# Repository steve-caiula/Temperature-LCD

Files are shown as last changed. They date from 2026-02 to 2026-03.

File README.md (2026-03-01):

# Temperature LCD - Bare-Metal AVR

A bare-metal C project for the ATmega328P. Custom 1-Wire and LCD drivers, no external libraries.

## Overview

This project implements a real-time temperature monitoring system on an ATmega328P microcontroller. The DS18B20 sensor communicates 
via a custom 1-Wire driver written from scratch, and the measured temperature is displayed on a TC1602A-01T LCD through a 
4-bit driver. A button switches between Celsius, Fahrenheit and Kelvin. No external application libraries. All drivers implemented 
from scratch via direct register manipulation, using only the avr-gcc toolchain.

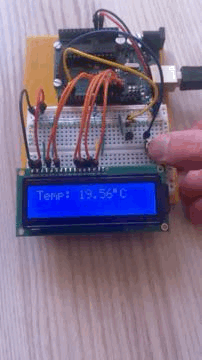
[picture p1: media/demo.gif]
Demo


For the video demo, see the `media/` folder.

## Hardware

The system is built around an Arduino Uno R3 (ATmega328P) connected to a DS18B20 temperature sensor and a 
TC1602A-01T 16x2 LCD display. The circuit is currently assembled on a breadboard.

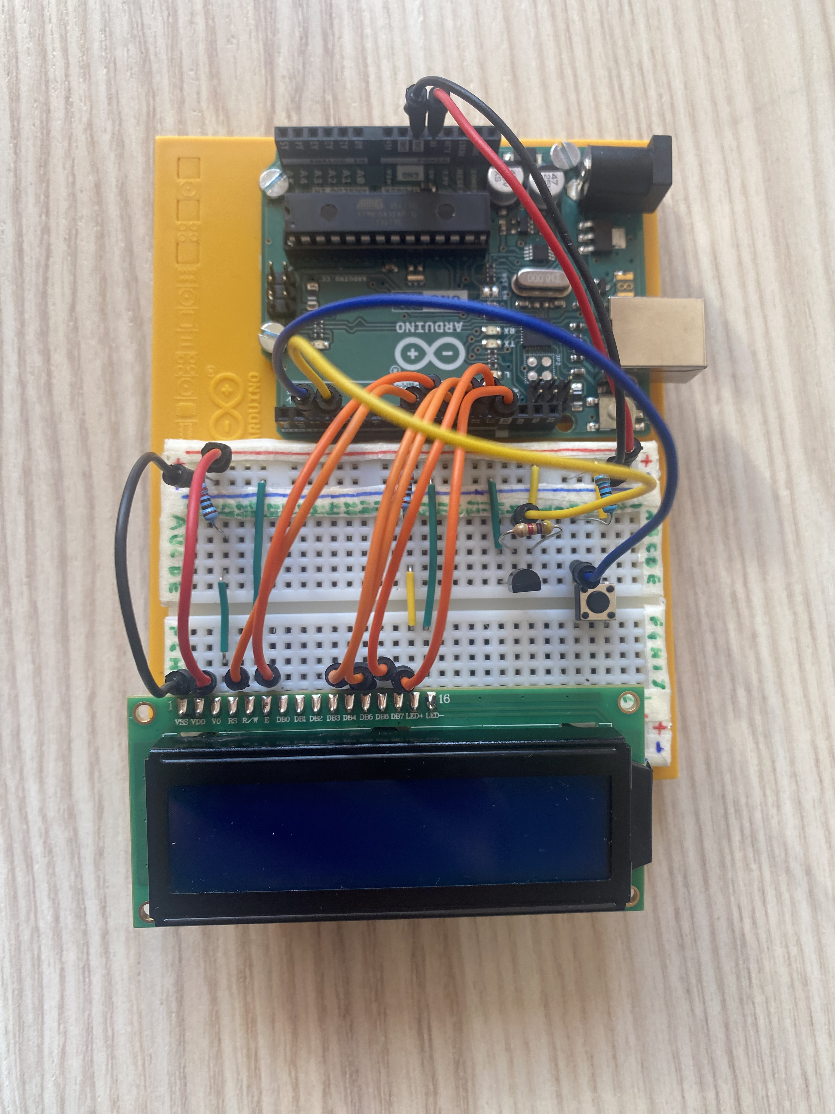
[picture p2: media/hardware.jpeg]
Hardware


### Components

| **Component** | **Quantity** | **Notes** |
| :--- | :--- | :--- |
| Arduino UNO R3 | 1 | ATmega328P @ 16MHz |
| DS18B20 | 1 | 1-Wire temperature sensor |
| TC1602A-01T | 1 | 16x2 LCD, 4-bit mode |
| Switch Button | 1 | |
| 10 kΩ Resistor | 1 | Button pull-down |
| 4.7 kΩ Resistor | 1 | 1-Wire bus pull-up |
| 220 Ω Resistor | 2 | LCD contrast and backlight |
| Jumper Wires | 17 | |
| Breadboard | 1 | 380 tie points |

### Schematic
The KiCad project file and a PDF version are available in the `hardware/` folder.

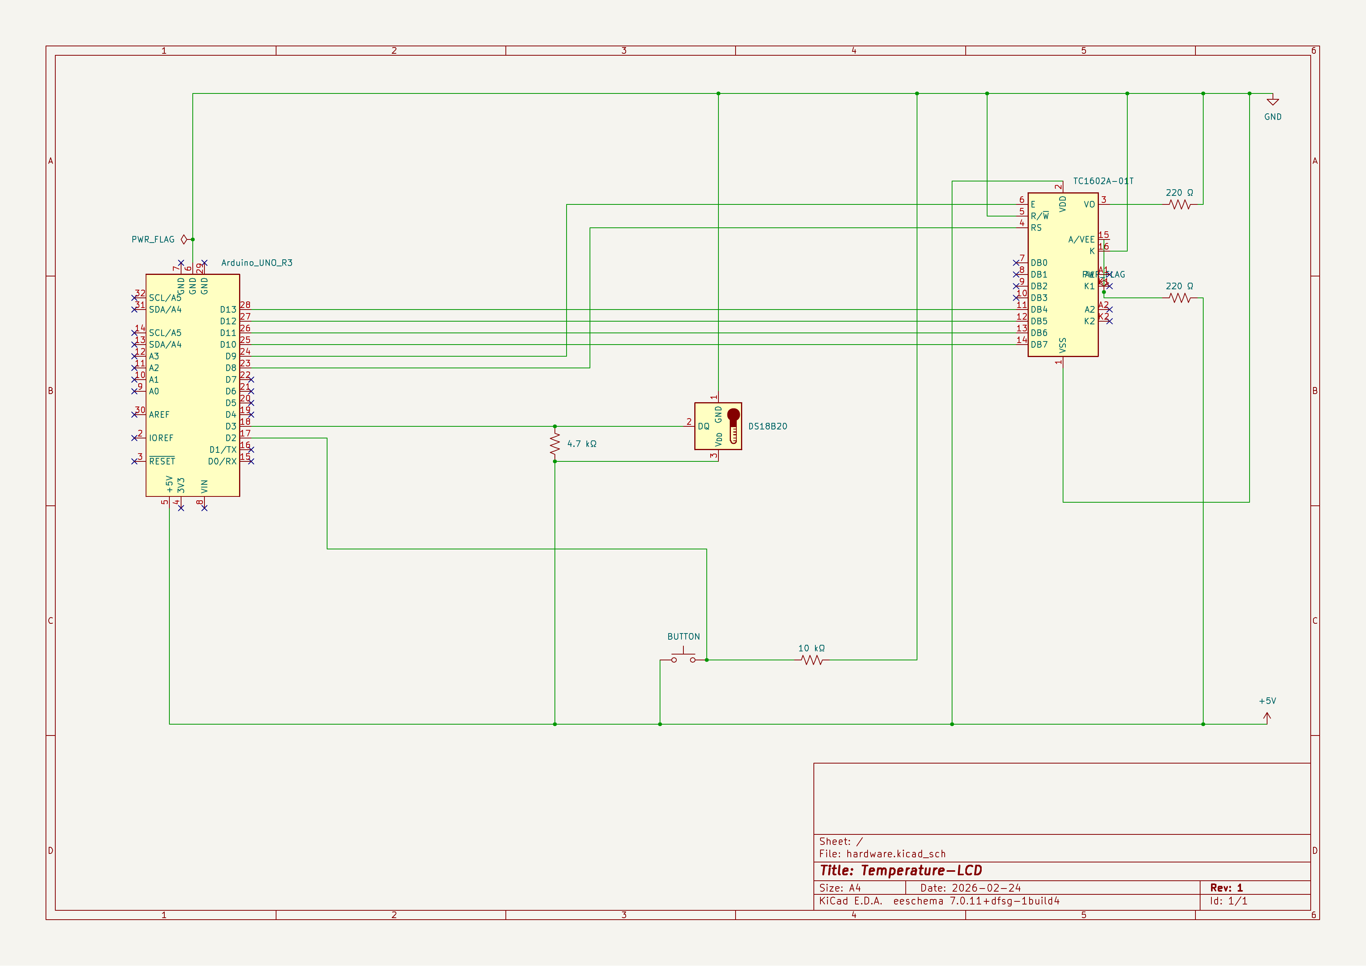
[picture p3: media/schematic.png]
Schematic


## Software
The firmware is organized into independent, single-responsibility modules. Each peripheral has a dedicated driver 
with a clean public interface, keeping hardware-specific code separate from application logic.

### Structure

| **File** | **Description** |
| :--- | :--- |
| src/main.c | System setup, GPIO/timer/interrupt configuration, main loop |
| src/temp_sensor.c | DS18B20 1-Wire driver: reset, bit/byte read-write, temperature conversion |
| src/lcd.c | TC1602A-01T 4-bit driver: initialization, cursor control, print |
| src/button.c | INT0 ISR with 200ms debounce, FSM state cycling |
| src/mcu_timer.c | Timer0 CTC ISR, atomic 32-bit millisecond counter |
| include/temp_sensor.h | DS18B20 command definitions and public driver interface |
| include/lcd.h | LCD command definitions, special characters, public driver interface |
| include/button.h | INT0 ISR declaration, unit_measure extern |
| include/mcu_timer.h | system_millis extern, get_millis() declaration |
| include/fsm_states.h | DisplayState enum: CELSIUS, FAHRENHEIT, KELVIN, SENSOR_ERROR |
| include/pin_definitions.h  | ATmega328P pin mapping for all peripherals |

### Protocols
The following section describes the two communication protocols implemented in this project and the key implementation decisions.

#### 1-Wire (DS18B20)
* **Reset and Presence Pulse:** Every communication starts with a 480us pulse, during which the master pulls the bus LOW. After the 
release, the master samples at 70us, instead of the 60us mentioned in the datasheet, in order to cover both slow and faster sensors 
during their guaranteed presence pulse window (60-240us).

* **Write and Read slot:** In Write 1 slot the master pulls the bus LOW and then releases it within 15us. The bus is pulled HIGH by 
the resistor for the remainder of the slot. Holding for 10us ensures the sensor detects the start but samples a HIGH state. In Write 0
the master pulls the bus LOW and holds it for the duration of the slot (minimum 60us). Holding for 55-60us ensures the sensor 
samples a LOW state during its 15-60us window. For Read slots, the master initiates with a 2us LOW pulse, then releases 
the bus and samples at 12us total, within the 15us datasheet limit, with a safety margin.

* **Asynchronous Conversion:** The DS18B20 sensor takes up to 750ms for a 12-bit conversion. Instead of blocking the system with a 
`_delay_ms(750)`, the function `get_raw_temperature()` uses a two-state FSM and the Timer0's millisecond counter to check the 
elapsed time without occupying the CPU. 

#### 4-bit (TC1602A-01T)
* **Initialization Sequence:** Wake up sequence requires three 0x03 nibbles with specific delays (> 4.1ms, > 100us) before switching 
to 4-bit mode. This is a fundamental requirement of the TC1602A-01T datasheet; without this sequence the peripheral would not 
correctly respond to the commands.

* **4-bit Transfer:** Each byte is divided into two 4-bit nibbles. High nibble (DB7-DB4) is sent first, then the low nibble (DB3-DB0).
The 4 bits get aligned to physical pins (PB2-PB5) with a left-shift of two positions before writing on PORTB.

* **Enable Pulse and Data Latch:** TC1602A-01T controller samples data on Enable signal's falling edge. HIGH pulse lasts for 1us,
higher than the 150ns in the datasheet, in order to guarantee compatibility with the slower units. After every nibble we wait for 
50us to let the controller process the data.

### Critical Sections
* **Atomic 32-bit read:** AVR is an 8-bit architecture while `system_millis` is a `uint32_t` and uses 32 bits, so the reading 
requires 4 CPU cycles. If the ISR updates `system_millis` during the reading, the data could be corrupted. `cli()` disables
every interrupt to protect the full 32-bit reading (4 CPU cycles), `sei()` re-enables the interrupts at the end of the reading 
operation.

* **1-Wire Timing Protection:** Protocol timing is critical and in the order of microseconds, an interrupt during the bit sequence 
would corrupt the communication. `cli()` disables every interrupt to protect the 1-Wire bit operations (`sensor_reset()`, 
`sensor_write_bit()`, `sensor_read_bit()`), `sei()` re-enables the interrupts at the end of the operation.

## Problems and resolutions
This section documents the key design decisions and problems encountered during development, along with their solutions.

### Blocking Delay During Temperature Conversion
Initially I used `_delay_ms(750)` to wait for DS18B20 conversion, but the system blocked for 750ms each cycle and the button did
not respond during this block. As a solution I implemented a two-state FSM in `get_raw_temperature()` using `get_millis()` to check 
the elapsed time without blocking the main loop, ensuring a responsive system.

### Sensor Error Handling
The original system had no way to detect a sensor's disconnection or malfunction, but it continued to show the last valid value 
without any error warning. As a solution I added the `sensor_reset()` return control, the sentinel value `TEMP_SENSOR_ERROR` 
(`INT16_MIN`), and the state `SENSOR_ERROR` in the FSM, which shows a warning message on the display. When the sensor gets 
re-inserted (or when it gets replaced with a new one, in case of malfunction), the system refreshes and restores the `CELSIUS` state.

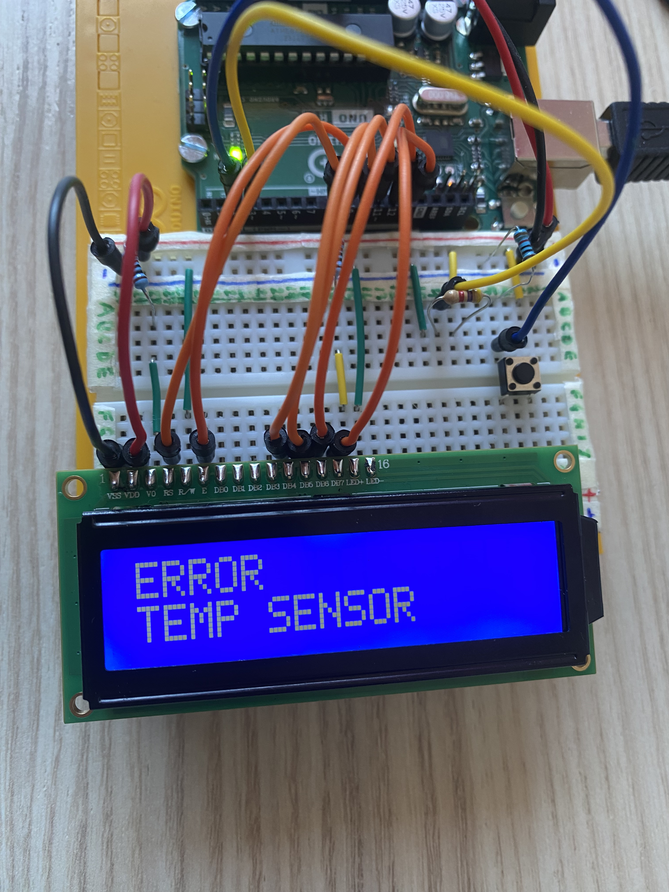
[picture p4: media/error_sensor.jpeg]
Sensor Error


### Microsecond Delays
I intentionally kept all the microsecond delays, and the millisecond delay in `lcd_initialization()`; the reason is that the 
microsecond delays are imperceptible and the millisecond ones in the initialization do not influence the performances because it 
happens only during the system's starting. Adding asynchronous handling for these cases would have increased the complexity
without any perceptible benefit. The main goal was the fluidity during a normal use, especially the button's immediate response.

### LCD Character Overflow
`lcd_print()` does not check the string's length before printing on the display. A possible overflow would write on the DDRAM
beyond the last visible character (16<sup>th</sup>), but the TC1602A-01T has 40 DDRAM cells per row with separate addresses for row 0 
and row 1, so an overflow does not compromise the adjacent row. The final spaces added to the strings overwrite possible residual 
characters from previous prints, avoiding visual artifacts without the use of `lcd_send_byte(LCD_CLEAR_DISPLAY, LCD_COMMAND)` at every
iteration.

## Installation and usage
The following instructions are tested on Linux. See the Makefile comments for macOS and Windows adjustments.

### Prerequisites
The following tools are required: `avr-gcc` and `avrdude`.

On Debian-based systems:
```bash
sudo apt install gcc-avr avrdude
```

### Clone and build
```bash
git clone https://github.com/steve-caiula/Temperature-LCD.git
cd Temperature-LCD
make
```

### Flash
Verify that the `PORT` variable in the Makefile matches your system before flashing. Then run:
```bash
make flash
```

To remove build artifacts:
```bash
make clean
```

### Usage
At startup, the display shows the temperature in Celsius. The button cycles through Celsius, Fahrenheit and Kelvin. 
If the sensor is disconnected or malfunctions, the display shows "ERROR / TEMP SENSOR". The system automatically 
restores the Celsius state when the sensor is reconnected.

## References

* [ATmega328P](https://ww1.microchip.com/downloads/en/DeviceDoc/Atmel-7810-Automotive-Microcontrollers-ATmega328P_Datasheet.pdf)
* [DS18B20](https://www.analog.com/media/en/technical-documentation/data-sheets/DS18B20.pdf)
* [TC1602A-01T](https://www.digikey.in/htmldatasheets/production/2410219/0/0/1/TC1602A-01T.pdf)
* [Arduino Uno R3 Pinout](https://docs.arduino.cc/resources/pinouts/A000066-full-pinout.pdf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)

## Author

Stefano Caiula 
* [GitHub](https://github.com/steve-caiula)
* [LinkedIn](https://www.linkedin.com/in/stefano-c-a76137258/)

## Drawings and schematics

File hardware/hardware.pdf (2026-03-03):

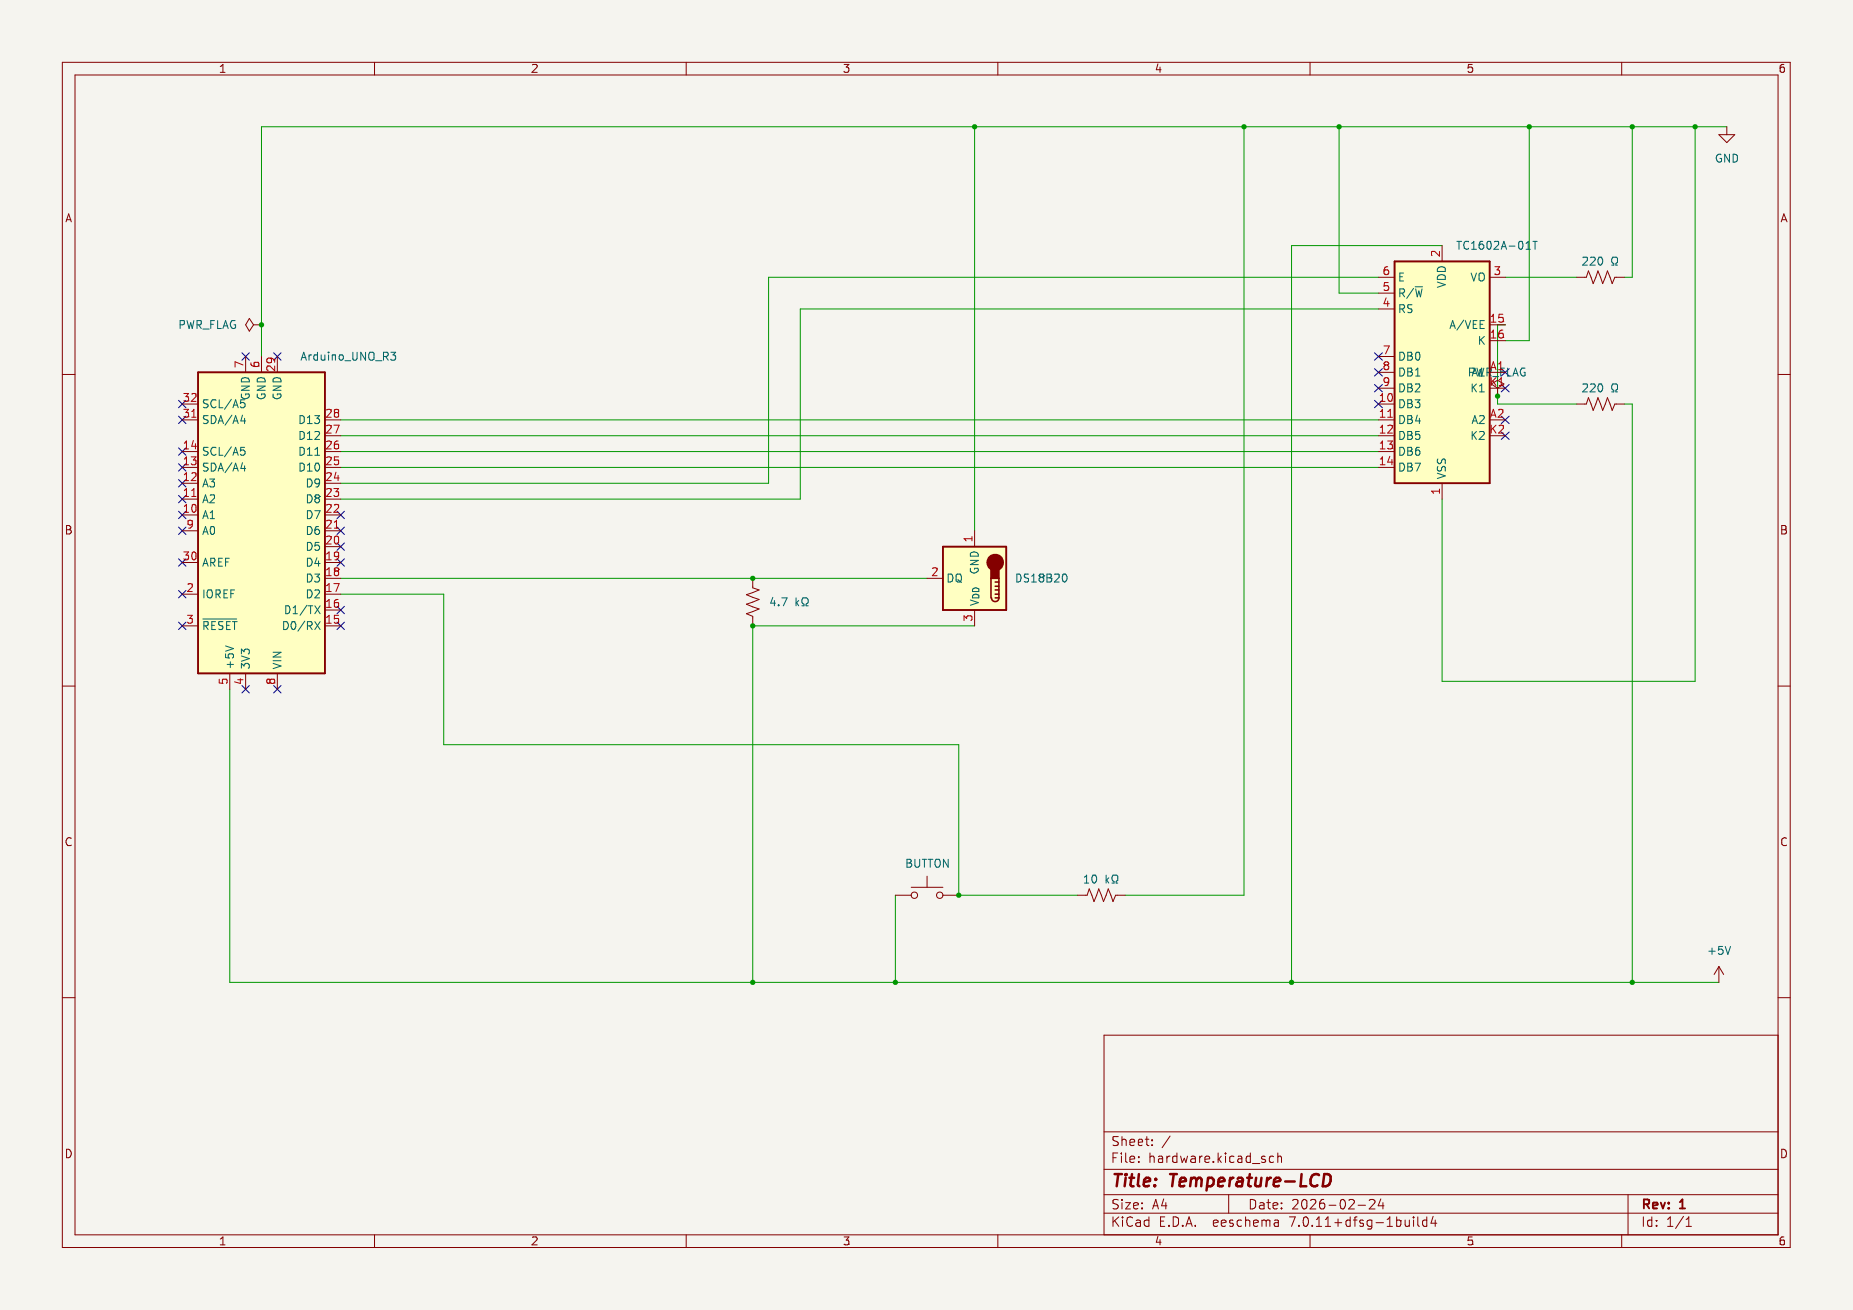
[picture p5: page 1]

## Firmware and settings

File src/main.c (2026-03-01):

#include <avr/io.h>
#include <avr/interrupt.h>
#include <util/delay.h>
#include <stdint.h>
#include <stdlib.h>
#include "pin_definitions.h"
#include "fsm_states.h"
#include "temp_sensor.h"
#include "lcd.h"
#include "button.h"



void setup (void)
{
    // --- GPIO CONFIGURATION ---

    DDRD &= ~(1 << TEMP_SENSOR); // TEMP_SENSOR (input). Set as input initially, OneWire protocol will toggle this

    DDRD &= ~(1 << BUTTON); // BUTTON (input)

    DDRB |= (1 << LCD_DB4) | (1 << LCD_DB5) | (1 << LCD_DB6) | (1 << LCD_DB7); // LCD Data Pins (output)

    DDRB |= (1 << LCD_RS) | (1 << LCD_E); // LCD Control Pins (output)

    
    
    // --- EXTERNAL INTERRUPT CONFIGURATION  (BUTTON) ---

    EIMSK |= (1 << INT0);                 // Enable external interrupt INT0
    EICRA |= (1 << ISC01) | (1 << ISC00); // Trigger INT0 on rising edge
    
    

    // --- TIMER0 CONFIGURATION (millis) ---
    
    TCCR0A |= (1 << WGM01);              // CTC mode
    TCCR0B |= (1 << CS01) | (1 << CS00); // Prescaler 64
    OCR0A = 249;                         // Comparison value (Formula: 16 MHz / 64 / 1000 Hz - 1)
    TIMSK0 |= (1 << OCIE0A);             // Enable interrupt for A comparison



    // --- ENABLE GLOBAL INTERRUPTS ---
    
    sei ();
}



int main (void)
{
    setup ();
    lcd_initialization();

    while (1)
    {
        int16_t raw_temperature = get_raw_temperature ();
        float temp_celsius = 0.0;
        float temp_fahrenheit = 0.0;
        float temp_kelvin = 0.0;
        char temp_string[10]; // In this string is saved the temperature value to avoid further conversions

        // Show ERROR warning incase of sensor's disconnection or malfunction (sensor not detected)
        if (raw_temperature == TEMP_SENSOR_ERROR) 
        {
            unit_measure = SENSOR_ERROR;
        }

        // Restore CELSIUS state when the sensor is detected and calculate temperature
        else 
        {
            if (unit_measure == SENSOR_ERROR)
            {
                lcd_send_byte (LCD_CLEAR_DISPLAY, LCD_COMMAND);
                _delay_ms(2);
                unit_measure = CELSIUS;
            }

            temp_celsius = convert_to_celsius (raw_temperature);
            temp_fahrenheit = convert_to_fahrenheit (temp_celsius);
            temp_kelvin = convert_to_kelvin (temp_celsius);
        }

        switch (unit_measure) 
        {
            case CELSIUS:
            lcd_set_cursor (0, 0);
            lcd_print ("Temp: ");
            dtostrf (temp_celsius, 4, 2, temp_string); 
            lcd_print (temp_string);
            lcd_send_byte (LCD_DEGREE_SYMBOL, LCD_DATA); // Print degree symbol '°'
            lcd_print ("C   ");
            break;

            case FAHRENHEIT:
            lcd_set_cursor (0, 0);
            lcd_print ("Temp: ");
            dtostrf (temp_fahrenheit, 4, 2, temp_string); 
            lcd_print (temp_string);
            lcd_send_byte (LCD_DEGREE_SYMBOL, LCD_DATA); // Print degree symbol '°'
            lcd_print ("F   ");
            break;

            case KELVIN:
            lcd_set_cursor (0, 0);
            lcd_print ("Temp: ");
            dtostrf (temp_kelvin, 4, 2, temp_string); 
            lcd_print (temp_string);
            lcd_print (" K  ");
            break;

            case SENSOR_ERROR:
            lcd_set_cursor (0, 0);
            lcd_print ("ERROR          ");
            lcd_set_cursor (1, 0);
            lcd_print ("TEMP SENSOR    ");
            break;
        }
    }
}

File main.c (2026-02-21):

#include <avr/io.h>
#include <avr/interrupt.h>
#include <util/delay.h>
#include <stdint.h>
#include "pin_definitions.h"
#include "fsm_states.h"
#include "temp_sensor.h"



// --- GLOBAL VARIABLES ---

volatile uint32_t system_millis = 0;          // Global millisecond counter updated by TIMER0
volatile DisplayState unit_measure = CELSIUS; // FSM state



// --- get_millis FUNCTION ---

uint32_t get_millis (void)
{
    /* 
       Returns the current millisecond count with atomic access.
       Since the AVR is an 8-bit architecture, reading a 32-bit variable (4 bytes)
       takes multiple CPU cycles. This function disables interrupts during the read
       to prevent the timer from updating the value mid-access, which would
       result in data corruption.
    */
    uint32_t ms_copy;        // Temporary variable

    cli ();                  // Disable interrupts to protect the 32-bit read
    ms_copy = system_millis; // Copy system_millis to a local variable while interrupts are disabled
    sei ();                  // Re-enable interrupts immediately after
    return ms_copy;          // Return the protected copy
}



// ---- ISR ----

ISR (INT0_vect)
{
    static uint32_t last_interrupt_time = 0; // Timestamp of the last valid button press (for debouncing) 
    uint32_t current_time = system_millis;   // Current time

    // Debounce management (200 millis)
    if (current_time - last_interrupt_time > 200)
    {
        unit_measure = (unit_measure + 1) % TOTAL_STATES; // Change FSM state
        last_interrupt_time = current_time;               // Update last button pressure time
    }
}

ISR (TIMER0_COMPA_vect)
{
    system_millis++; // + 1 millis
}



void setup (void)
{
    // --- GPIO CONFIGURATION ---

    DDRD &= ~(1 << TEMP_SENSOR);             // TEMP_SENSOR (input). Set as input initially, OneWire protocol will toggle this

    DDRD &= ~(1 << BUTTON);                  // BUTTON (input)

    DDRD |= (1 << LCD_DB4) | (1 << LCD_DB5); // LCD Data Pins (output)
    DDRB |= (1 << LCD_DB6) | (1 << LCD_DB7); // LCD Data Pins (output)

    DDRD |= (1 << LCD_RS) | (1 << LCD_E);    // LCD Control Pins (output)

    
    
    // --- EXTERNAL INTERRUPT CONFIGURATION  (BUTTON) ---

    EIMSK |= (1 << INT0);                 // Enable external interrupt INT0
    EICRA |= (1 << ISC01) | (1 << ISC00); // Trigger INT0 on rising edge
    
    

    // --- TIMER0 CONFIGURATION (millis) ---
    
    TCCR0A |= (1 << WGM01);              // CTC mode
    TCCR0B |= (1 << CS01) | (1 << CS00); // Prescaler 64
    OCR0A = 249;                         // Comparison value (Formula: 16 MHz / 64 / 1000 Hz - 1)
    TIMSK0 |= (1 << OCIE0A);             // Enable interrupt for A comparison



    // --- ENABLE GLOBAL INTERRUPTS ---
    
    sei ();
}



int main (void)
{
    setup ();

    while (1)
    {
        int16_t raw_temperature = get_raw_temperature ();
        float temp_celsius = convert_to_celsius (raw_temperature);

        switch (unit_measure) 
        {
            case CELSIUS:
            break;

            case FAHRENHEIT:
            break;

            case KELVIN:
            break;

            default:
            break;
        }
    }
}

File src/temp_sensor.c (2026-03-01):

#include <avr/io.h>
#include <stdint.h>
#include <avr/interrupt.h>
#include <util/delay.h>
#include "temp_sensor.h"
#include "pin_definitions.h"
#include "mcu_timer.h"




uint8_t sensor_reset (void)
{
    uint8_t detected = 0;

    cli (); // Critical Section Start: Disable interrupts to protect 1-Wire timing

    // --- PHASE 1: MASTER TRANSMITS RESET PULSE ---

    DDRD |= (1 << TEMP_SENSOR);   // Set pin as output
    PORTD &= ~(1 << TEMP_SENSOR); // Pull bus LOW
    _delay_us(480);           // Wait time for reset 



    // --- PHASE 2: MASTER REALESES BUS AND WAITS FOR PRESENCE PULSE ---

    DDRD &= ~(1 << TEMP_SENSOR);  // Release bus (set as input)
    
    /* 
       Wait 70us to sample the bus.
       The datasheet states that the sensor waits 15-60us before pulling the bus LOW
       for 60-240us. Sampling at 70us ensures we catch both fast and slow sensors
       during their guaranteed presence pulse window.
    */
    _delay_us (70);



    // --- PHASE 3: SAMPLE THE BUS TO DETECT THE SENSOR ---

    if (!(PIND & (1 << TEMP_SENSOR))) 
    {
        detected = 1; // Sensor pulled the bus LOW (Presence Pulse found)
    }

    else 
    {
        detected = 0;
    }

    /* 
       Recovery time: Wait for the remainder of the 480us time slot.
       This ensures the sensor has finished its presence pulse (max 240us)
       and the bus has stabilized before the next communication starts.
    */
    _delay_us (410);  
    
    sei ();          // Critical Section End: Re-enable interrupts

    return detected; // Return 1 if the sensor is detected, 0 otherwise
}




static void sensor_write_bit (uint8_t bit_value)
{
    cli (); // Atomic Block Start: Prevent interrupt interference during write slot
    
    // Every write slot starts by pulling the bus LOW
    DDRD |= (1 << TEMP_SENSOR);    // Set pin as output
    PORTD &= ~(1 << TEMP_SENSOR);  // Pull bus LOW


    
    /* 
       Write 1 slot: The master pulls the bus LOW and then releases it 
       within 15us. The bus is pulled HIGH by the resistor for the 
       remainder of the slot. Holding for 10us ensures the sensor 
       detects the start but samples a HIGH state.
    */
    if (bit_value) 
    {
        _delay_us (10);           // Keep bus LOW for short amount of time
        DDRD &= ~(1 << TEMP_SENSOR); // Release bus (set as input)
        _delay_us (50);           // Recovery time
    }



    /* 
       Write 0 slot: The master pulls the bus LOW and holds it for 
       the duration of the slot (minimum 60us). Holding for 55-60us 
       ensures the sensor samples a LOW state during its 15-60us window.
    */
    else 
    {
        _delay_us (55);           // Keep bus LOW for almost the whole slot time
        DDRD &= ~(1 << TEMP_SENSOR);  // Release bus (set as input)
        _delay_us (5);            // Recovery time
    }

    sei (); // Atomic Block End

    /* 
       Global recovery time: The dasheet states that the sensor needs a
       minimum of a 1us recovery time between individual write slots.
    */
    _delay_us (2);               // This ensures at least 2us of HIGH bus between any two bits
}




static void sensor_write_byte (uint8_t data)
{
    // Loop 8 times to read each bit of the byte
    for (uint8_t i = 0; i < 8; i++) 
    {
        sensor_write_bit(data & 0x01); // Isolate bit
        data >>= 1;                              // Shift bit
    }
}




static uint8_t sensor_read_bit (void)
{
    uint8_t bit_value = 0;

    cli (); // Atomic Block Start: Protect the timing-sensitive sampling window

    /* 
       Every read slot is initiated by the master pulling the bus LOW 
       for a minimum of 1us. We hold it for 2us to ensure the sensor 
       detects the start of the slot (TINIT).
    */
    DDRD |= (1 << TEMP_SENSOR);    // Set pin as output
    PORTD &= ~(1 << TEMP_SENSOR);  // Pull bus LOW
    _delay_us(2);
    


    /* 
       After the initial pulse, the master must release the bus so the 
       sensor can take control. We then wait for the signal to stabilize.
       The datasheet states data is valid for 15us from the start of the slot.
    */
    DDRD &= ~(1 << TEMP_SENSOR);   // Release bus (set as input)
    _delay_us (10);

    
    
    /* 
       The master must sample within 15us from the falling edge. 
       Having already waited 2us, an additional 10us delay brings us 
       to 12us total. This provides a safety margin, sampling just 
       before the 15us limit (TSAMPLE).
    */
    if (PIND & (1 << TEMP_SENSOR))
    {
        bit_value = 1;
    }

    // else: do nothing as the bit is already 0 by default

    
    
    /* 
       The total time slot must be at least 60us. 
       We wait the remaining time (approx 50us) to complete the slot 
       and allow the mandatory recovery time before the next operation.
    */
    _delay_us (50);



    sei (); // Atomic Block End

    /* 
       Global recovery time: The datasheet states a minimum of 1us 
       is required between individual slots to let the bus stabilize.
    */
    _delay_us (2);

    return bit_value;
}




static uint8_t sensor_read_byte (void)
{
    uint8_t scratchpad_byte = 0; // Temporary container for the received byte

    // Loop 8 times to read each bit of the byte
    for (uint8_t i = 0; i < 8; i++) 
    {
        uint8_t bit = sensor_read_bit();
        
        if (bit == 1) 
        {
            // The DS18B20 transmits the Least Significant Bit (LSB) first

            scratchpad_byte |= (1 << i); // Set the i-th bit of scratchpad_byte
        }

        // else: do nothing as the bit is already 0 by default
    }

    return scratchpad_byte;
}
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

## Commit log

2026-02-14 Initial commit: setup Temperature-LCD (AVR)
2026-02-19 feat: implement datasheet-compliant OneWire driver and interrupt-driven FSM architecture
2026-02-20 feat(sensor): complete DS18B20 1-Wire driver
2026-02-21 feat: complete DS18B20 driver with interrupt protection
2026-02-23 refactor temp_sensor: implement non-blocking temperature acquisition
2026-02-24 hw: complete KiCad schematic
    [circuit_schematic.kicad_sch]
2026-02-24 hw: correct schematic
    [hardware_schematic.kicad_sch]
2026-03-01 Add README, error handling, atomic read fix and architecture cleanup
    [hardware_schematic.kicad_sch]
2026-03-03 correct schematic
    [hardware.kicad_sch]
